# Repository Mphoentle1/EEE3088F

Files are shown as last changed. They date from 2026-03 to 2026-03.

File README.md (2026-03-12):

# EEE3088F
DoA project

This project involves the design and implementation of a high-precision acoustic sensor capable of determining the Direction of Arrival (DoA) of a specific 2000 Hz beacon. The system integrates custom analog front-end hardware with a high-performance STM32F429ZGT6 microcontroller to process signals in real-time under strict latency constraints.

Technical Specifications

Target Frequency: 2000 Hz 
Sampling Rate: 20,000 Hz (5x oversampling for phase accuracy) 
Microphone Spacing: 50 mm
Supply Voltage: 3.3V DC (Strictly compliant with Automated Testing Rig) 
Communication: I2C Slave (Address: 0x42) 
Latency Ceiling: < 50ms from trigger to DoA result 

System Architecture

Analog Front-End
The signal chain uses a Zilltek ZTS6618 top-ported MEMS microphone for superior assembly reliability. The analog path includes:
AC Coupling: Blocks microphone DC offset.Active 
Bandpass Filter: A Multiple Feedback (MFB) topology using the AD8605 rail-to-rail op-amp, providing ~40dB of gain.
DC Biasing: Centering the signal at 1.65V for unipolar ADC sampling.
Digital ProcessingADC Acquisition: High-speed sampling triggered by the Rig state-machine.
DSP Algorithm: Cross-correlation (CCF) performed on the STM32's hardware Floating Point Unit (FPU) to calculate the time-of-flight difference between the microphone pair.
Register Interface: Results are reported via 32-bit IEEE 754 float registers.

📂 Repository Structure

/Hardware: KiCad PCB files, LTspice simulations, and Bill of Materials (BOM).
/Firmware: STM32CubeIDE project (C code), including CMSIS-DSP implementation.
/instruction_sheets: M1 Technical Contract and Physics Baseline proofs.

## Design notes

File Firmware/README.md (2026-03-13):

# DOA Sensor Firmware Implementation Flow

This document outlines the high-level architecture and implementation flow for the Direction of Arrival (DOA) sensor firmware in C/C++.

## 1. Initialization Phase (Startup)

Before accessing peripheral registers, the system must be properly configured.

*   **System Clock & Power:** Enable the system clocks for specific peripherals (ADC, I2C, DMA, GPIO).
*   **GPIO Configuration:**
    *   Set ADC pins to **Analog Input**.
    *   Set I2C pins to **Alternate Function** (SDA/SCL) and configure pull-up resistors if necessary.
*   **I2C Initialization:** Configure the I2C peripheral (slave address, speed, interrupts). This must be done early so it is ready to receive read requests from the external computer at any time.

## 2. ADC Setup Phase

*   **Enable & Calibrate:** Enable the ADC peripheral. Execute a calibration routine immediately after power-on to ensure measurement accuracy.
*   **Configure ADC:** Set the resolution, sampling time, and trigger source.
*   **DMA Configuration (Highly Recommended):** For DOA calculations, high-speed sampling of multiple channels (microphones) is required. Configure a Direct Memory Access (DMA) controller to automatically transfer data from the ADC register to a buffer in memory. This frees the CPU from polling and reading every single sample.

## 3. The Main Execution Loop (State Machine)

*   **Start Sampling:** Trigger the ADC conversion to begin filling the DMA buffer.
*   **Wait for Completion:**
    *   Implement an **Interrupt Service Routine (ISR)** (e.g., `ADC_ConvCpltCallback` or a DMA transfer complete interrupt).
    *   Inside the interrupt, set a volatile flag (`dataReady = true`).
*   **Signal Processing:**
    *   In the main loop, check if `dataReady` is true.
    *   If true, reset the flag and perform the DOA mathematics (FFT, Phase difference calculation, etc.) on the sampled data buffer.
    *   Update a global structure or array with the calculated Angle, Phase, and the Student Number.
    *   *Note: Ensure this structure is updated atomically or double-buffered so the I2C interrupt doesn't read partially updated data.*

## 4. Communication (Asynchronous)

*   **I2C Handling:** Communication with the external computer runs asynchronously in the background via interrupts.
*   **I2C Interrupt Handler:** When the external computer requests a read:
    *   The I2C ISR accesses the global result buffer (Angle, Phase, Student Number).
    *   It transmits this data back to the master.
    *   If a calculation is currently modifying the data, ensure proper data locking/buffering logic is in place.

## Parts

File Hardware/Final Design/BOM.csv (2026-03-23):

Comment | Designator | Footprint | LCSC | Quantity
100K | Rf1,Rf3 | R0805 (RESISTOR) | C149504 | 2
100nF | C12,C13,C14,C15,C16,C23,C24,C25,C26,C27,C5,C6,Cbias1,Cbias2,Cin1,Cin2 | C0805 (CAPACITOR) | C28233 | 16
10K | R1,R15,R16,R17,R2 | R0805 (RESISTOR) | C17414 | 5
10nF | C2,C3,C30,C31 | C0805 (CAPACITOR) | C1710 | 4
10uF | C1,C29,C7 | C0805 (CAPACITOR) | C15850 | 3
1K | Rf2,Rf6 | R0805 (RESISTOR) | C17513 | 2
2.2uF | C11,C4 | C0805 (CAPACITOR) | C377773 | 2
2.7K | Rg2,Rg9 | R0805 (RESISTOR) | C17530 | 2
3.3K | Rg1,Rg3 | R0805 (RESISTOR) | C26010 | 2
4.7K | R3,R9 | R0805 (RESISTOR) | C17673 | 2
4.7uF | C28 | C0805 (CAPACITOR) | C1779 | 1
82K | Rf4,Rf5,Rg4,Rg8 | R0805 (RESISTOR) | C23254 | 4
AD8606ARZ | U1,U4,U5,U6 | AD8606ARZ-REEL7 (OPAMP) | C22365308 | 4
CMM-2718AT-42308-TR | MIC1,MIC2 | XDCR_CMM-2718AT-42308-TR (MIC) | C3171756 | 2
STM32F429ZGTx | U11 | LQFP-144_20x20mm_P0.5mm | C46525 | 1

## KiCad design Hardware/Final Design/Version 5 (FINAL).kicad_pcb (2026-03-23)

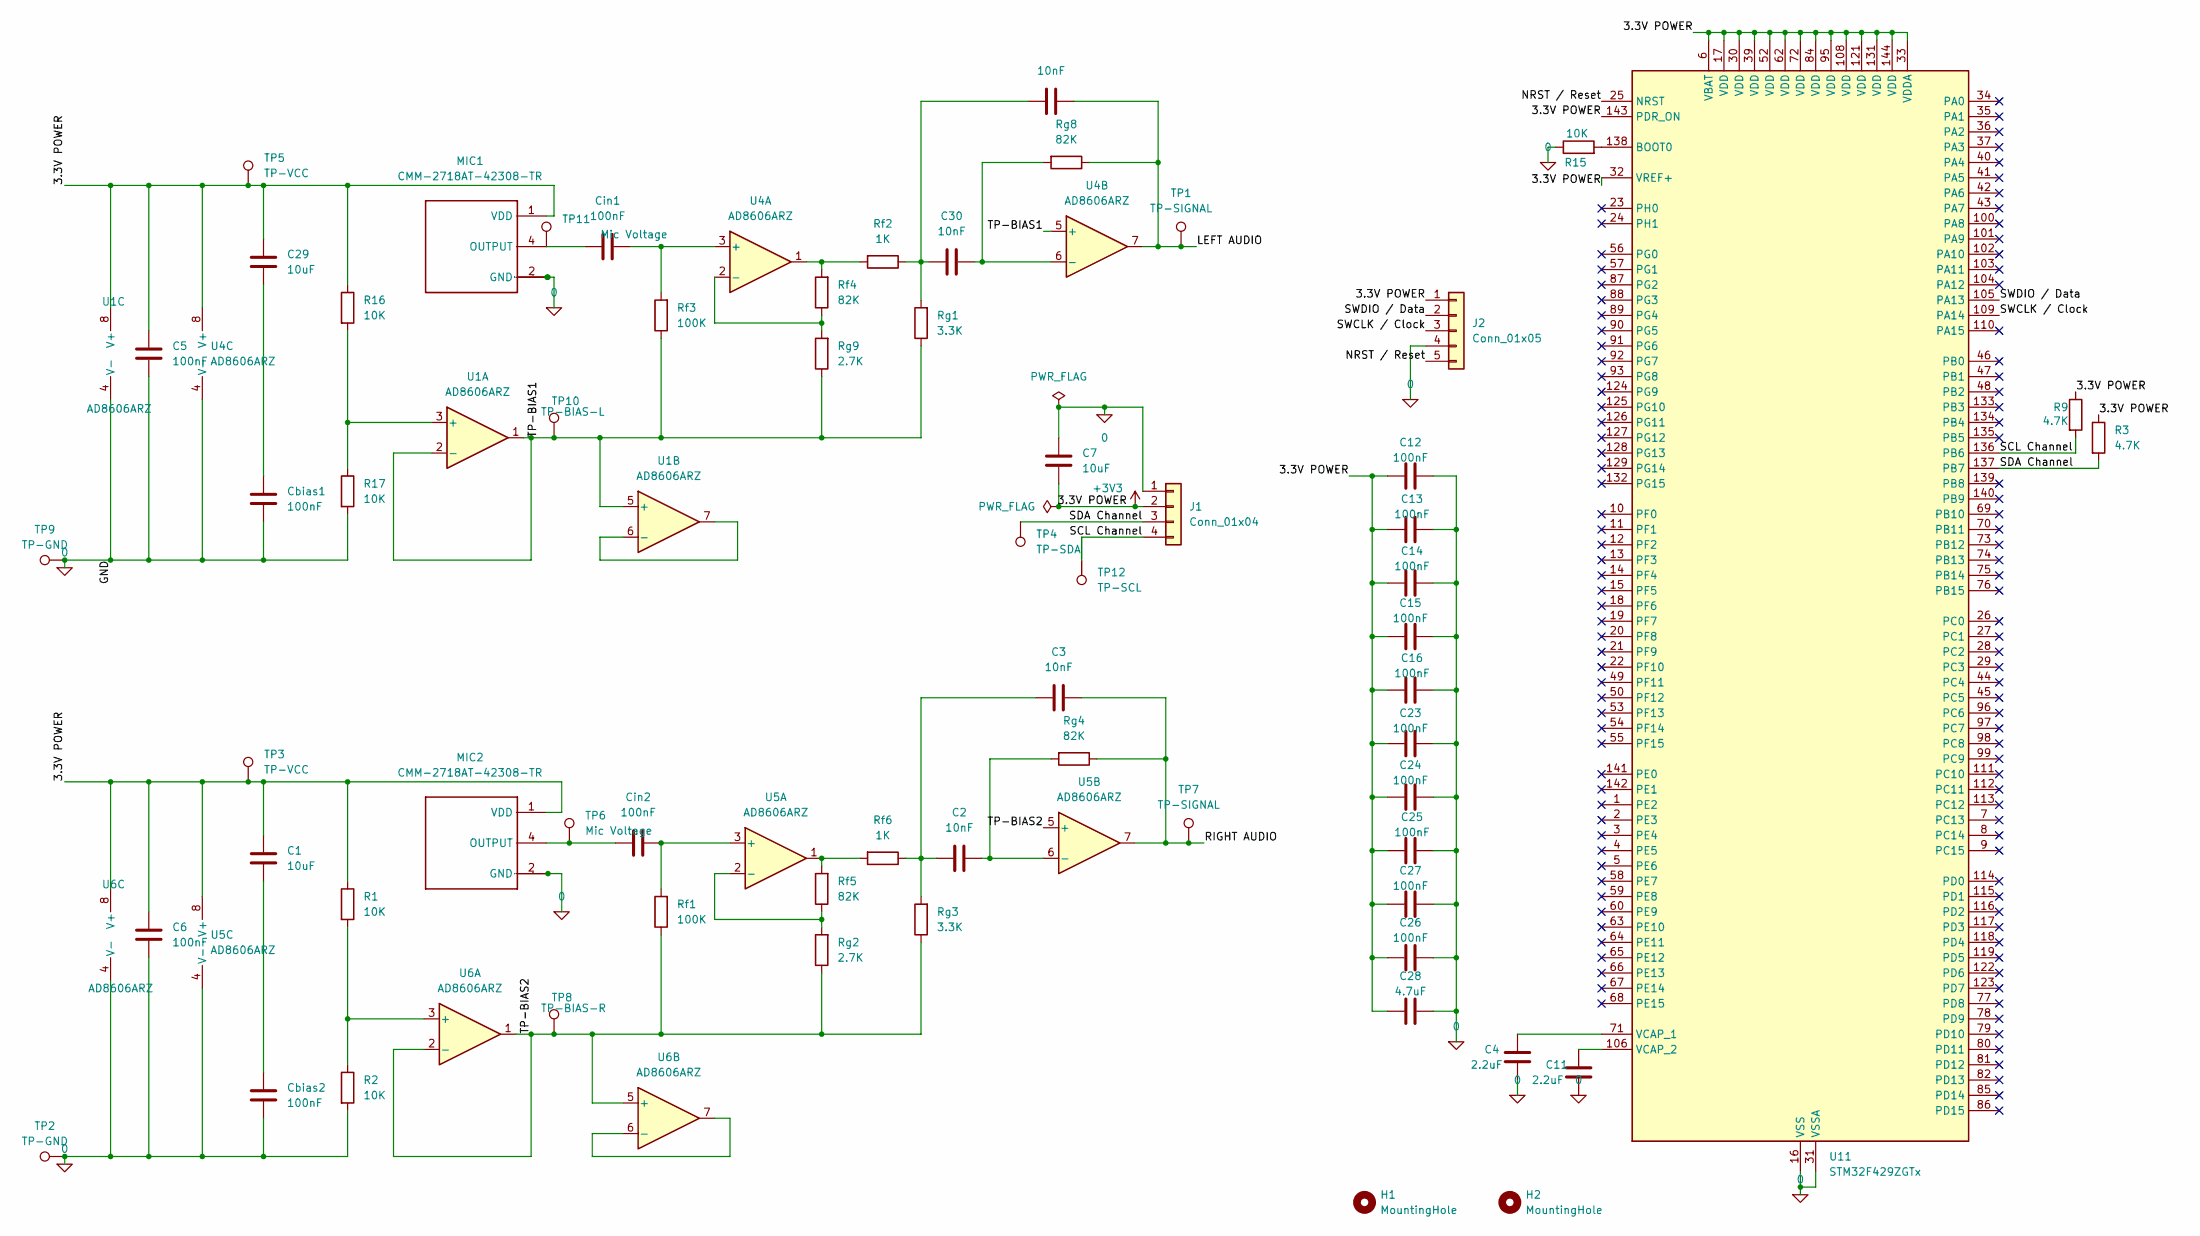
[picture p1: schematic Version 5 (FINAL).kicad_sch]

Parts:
C1, C7, C29: 10uF; C0805 (CAPACITOR); LCSC C1713
C2, C3, C30, C31: 10nF; C0805 (CAPACITOR); LCSC C24666
C4, C11: 2.2uF; C0805 (CAPACITOR); LCSC C1731
C5, C6, C12, C13, C14, C15, C16, C23, C24, C25, C26, C27: 100nF; C0805 (CAPACITOR); LCSC C29926
C28: 4.7uF; C0805 (CAPACITOR); LCSC C1746
Cbias1, Cbias2: 100nF; C0805 (CAPACITOR); LCSC C29926
Cin1, Cin2: 100nF; C0805 (CAPACITOR); LCSC C29926
H1, H2: MountingHole; MountingHole_3.2mm_M3
J1: Conn_01x04; PinHeader_1x04_P2.54mm_Horizontal
J2: Conn_01x05; PinHeader_1x05_P2.54mm_Vertical
MIC1, MIC2: CMM-2718AT-42308-TR; XDCR_CMM-2718AT-42308-TR (MIC); LCSC C3171756
R1, R2, R15, R16, R17: 10K; R0805 (RESISTOR); LCSC C84376
R3, R9: 4.7K; R0805 (RESISTOR); LCSC C17673
Rf1, Rf3: 100K; R0805 (RESISTOR); LCSC C96346
Rf2, Rf6: 1K; R0805 (RESISTOR); LCSC C2904551
Rf4, Rf5: 82K; R0805 (RESISTOR); LCSC C101876
Rg1, Rg3: 3.3K; R0805 (RESISTOR); LCSC C26010
Rg2, Rg9: 2.7K; R0805 (RESISTOR); LCSC C101616
Rg4, Rg8: 82K; R0805 (RESISTOR); LCSC C101876
TP1, TP7: TP-SIGNAL; TestPoint_Pad_2.0x2.0mm
TP2, TP9: TP-GND; TestPoint_Pad_2.5x2.5mm
TP3, TP5: TP-VCC; TestPoint_Pad_2.0x2.0mm
TP4: TP-SDA; TestPoint_Pad_2.0x2.0mm
TP6, TP11: Mic Voltage; TestPoint_Pad_2.0x2.0mm
TP8: TP-BIAS-R; TestPoint_Pad_2.0x2.0mm
TP10: TP-BIAS-L; TestPoint_Pad_2.0x2.0mm
TP12: TP-SCL; TestPoint_Pad_2.0x2.0mm
U1, U4, U5, U6: AD8606ARZ; AD8606ARZ-REEL7 (OPAMP); LCSC C22365308
U11: STM32F429ZGTx; LQFP-144_20x20mm_P0.5mm; LCSC C46525

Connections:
0: C4.1, C5.2, C6.2, C7.2, C11.1, C12.2, C13.1, C14.2, C15.2, C16.2, C23.2, C24.2, C25.2, C26.2, C27.2, C28.2, Cbias1.2, Cbias2.2, J1.1, J2.4, MIC1.2 (GND), MIC1.3 (GND), MIC2.2 (GND), MIC2.3 (GND), R2.2, R15.1, R17.2, TP2.1, TP9.1, U1.4 (V-), U4.4 (V-), U5.4 (V-), U6.4 (V-), U11.16 (VSS), U11.31 (VSSA), U11.38 (VSS), U11.51 (VSS), U11.61 (VSS), U11.83 (VSS), U11.94 (VSS), U11.107 (VSS), U11.120 (VSS), U11.130 (VSS)
+3V3: C1.1, C5.1, C6.1, C7.1, C12.1, C13.2, C14.1, C15.1, C16.1, C23.1, C24.1, C25.1, C26.1, C27.1, C28.1, C29.1, J1.2, J2.1, MIC1.1 (VDD), MIC2.1 (VDD), R1.1, R3.1, R9.1, R16.1, TP3.1, TP5.1, U1.8 (V+), U4.8 (V+), U5.8 (V+), U6.8 (V+), U11.6 (VBAT), U11.17 (VDD), U11.30 (VDD), U11.32 (VREF+), U11.33 (VDDA), U11.39 (VDD), U11.52 (VDD), U11.62 (VDD), U11.72 (VDD), U11.84 (VDD), U11.95 (VDD), U11.108 (VDD), U11.121 (VDD), U11.131 (VDD), U11.143 (PDR_ON), U11.144 (VDD)
/LEFT AUDIO: C31.2, Rg8.1, TP1.1, U4.7
/NRST / Reset: J2.5, U11.25 (NRST)
/RIGHT AUDIO: C3.2, Rg4.1, TP7.1, U5.7
/SCL Channel: J1.4, R9.2, TP12.1, U11.136 (PB6)
/SDA Channel: J1.3, R3.2, TP4.1, U11.137 (PB7)
/SWCLK / Clock: J2.3, U11.109 (PA14)
/SWDIO / Data: J2.2, U11.105 (PA13)
/TP-BIAS1: Rf3.1, Rg1.1, Rg9.1, TP10.1, U1.1, U1.2 (-), U1.5 (+), U4.5 (+)
/TP-BIAS2: Rf1.1, Rg2.1, Rg3.1, TP8.1, U5.5 (+), U6.1, U6.2 (-), U6.5 (+)
unnamed: C1.2, Cbias2.1
unnamed: C2.1, C3.1, Rf6.1, Rg3.2
unnamed: C29.2, Cbias1.1
unnamed: C30.1, C31.1, Rf2.1, Rg1.2
unnamed: Cin1.1, MIC1.4 (OUTPUT), TP11.1
unnamed: Cin2.1, MIC2.4 (OUTPUT), TP6.1
unnamed: Rf2.2, Rf4.2, U4.1
unnamed: Rf5.2, Rf6.2, U5.1
unnamed: R16.2, R17.1, U1.3 (+)
unnamed: U1.6 (-), U1.7
unnamed: Cin1.2, Rf3.2, U4.3 (+)
unnamed: Rf4.1, Rg9.2, U4.2 (-)
unnamed: C30.2, Rg8.2, U4.6 (-)
unnamed: Cin2.2, Rf1.2, U5.3 (+)
unnamed: Rf5.1, Rg2.2, U5.2 (-)
unnamed: C2.2, Rg4.2, U5.6 (-)
unnamed: R1.2, R2.1, U6.3 (+)
unnamed: U6.6 (-), U6.7
unnamed: R15.2, U11.138 (BOOT0)
unnamed: C4.2, U11.71 (VCAP_1)
unnamed: C11.2, U11.106 (VCAP_2)

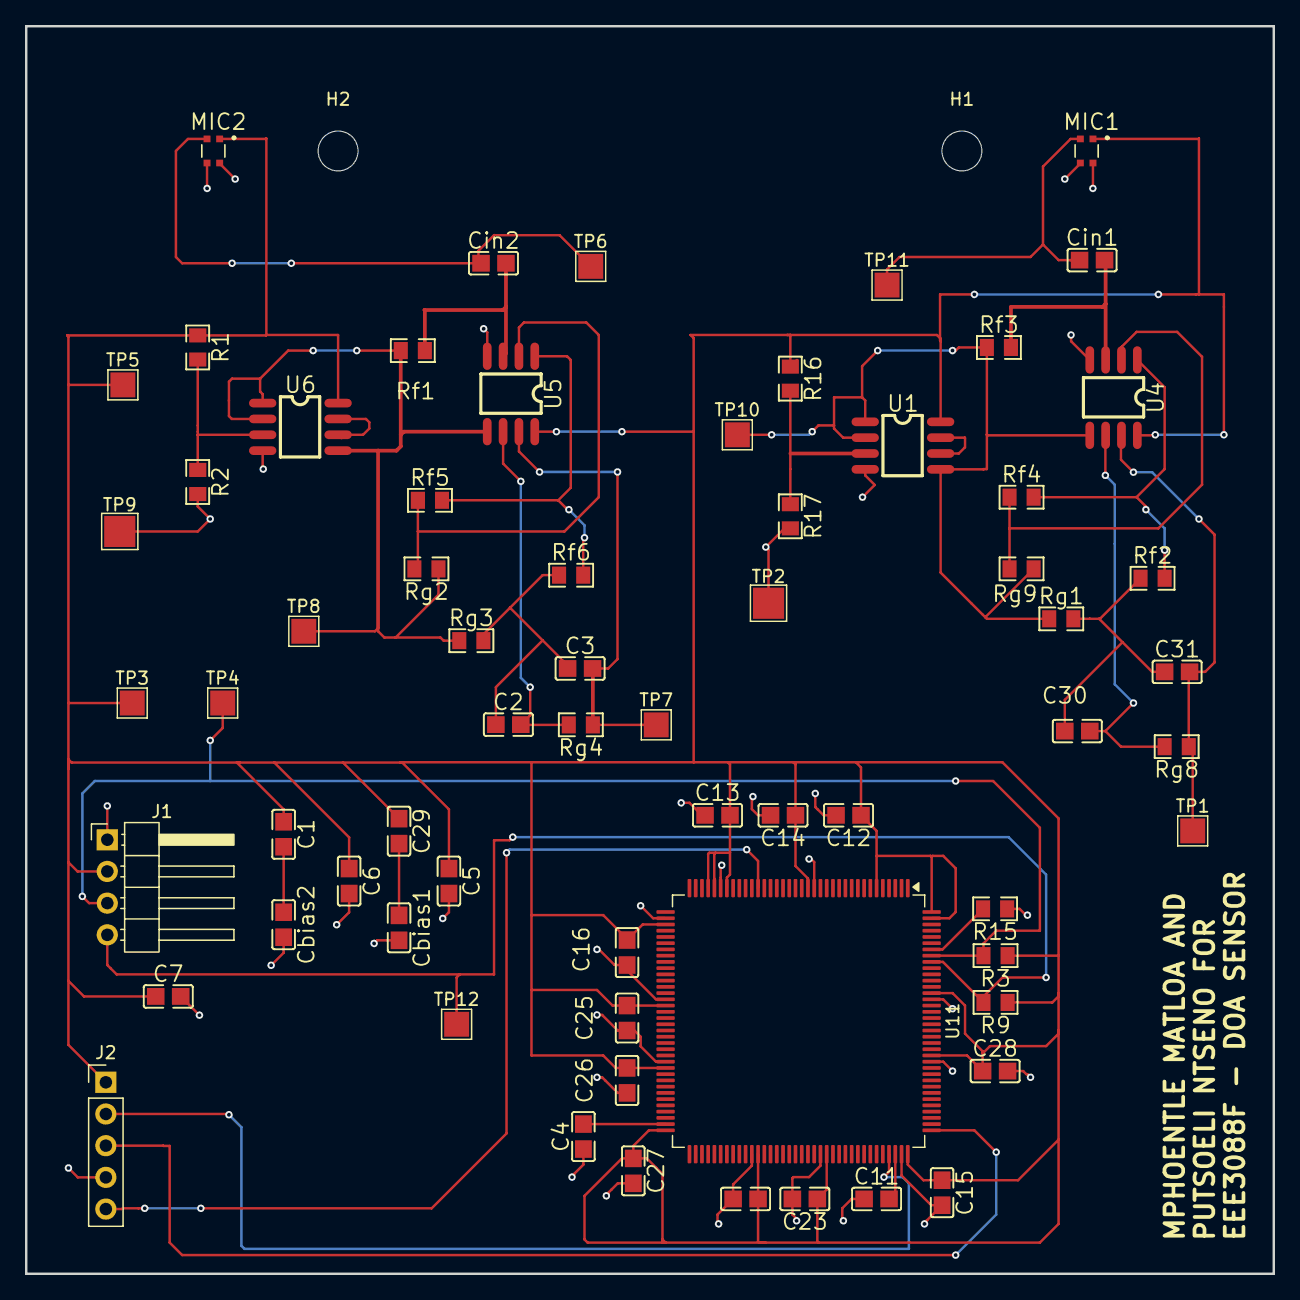
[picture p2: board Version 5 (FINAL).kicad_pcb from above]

Board: 2 copper layers, 100.0 x 100.0 mm, 68 parts (0 on the bottom side), 32 nets.

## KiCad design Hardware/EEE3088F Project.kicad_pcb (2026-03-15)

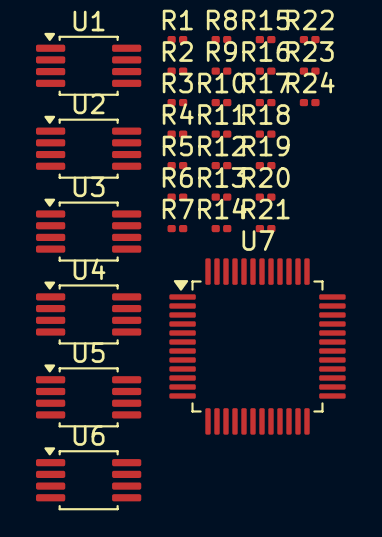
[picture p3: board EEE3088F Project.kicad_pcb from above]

Board: 2 copper layers, 31 parts (0 on the bottom side), 24 nets, no tracks yet.

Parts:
R1, R2, R3, R4, R6, R7, R9, R10, R12, R14, R16, R17, R18, R20, R23: 10K; R_0201_0603Metric
R5, R8, R11, R13, R15, R19, R24: 100K; R_0201_0603Metric
R21, R22: 100; R_0201_0603Metric
U1, U2, U3, U4, U5, U6: OP1177ARM; MSOP-8_3x3mm_P0.65mm
U7: STM32F051C6Tx; LQFP-48_7x7mm_P0.5mm

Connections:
0: R2.2, R4.2, R23.1, U1.4 (V-), U2.4 (V-), U3.4 (V-), U4.4 (V-), U5.4 (V-), U6.4 (V-), U7.8 (VSSA), U7.23 (VSS), U7.47 (VSS)
+3.3V: R1.1, R3.1, R24.2, U1.7 (V+), U2.7 (V+), U3.7 (V+), U4.7 (V+), U5.7 (V+), U7.1 (VBAT), U7.9 (VDDA), U7.24 (VDD), U7.48 (VDD)
/LEFT AUDIO: R5.1, R22.2, U6.6
/RIGHT AUDIO: R19.1, R21.2, U5.6
/SDA Channel: R24.1, U7.43 (PB7)
unnamed: R1.2, R2.1, R9.2
unnamed: R3.2, R4.1, R10.2
unnamed: R11.1, R18.1, U2.6
unnamed: R15.1, R17.1, U1.6
unnamed: R9.1, U1.3 (+)
unnamed: R15.2, R16.1, U1.2 (-)
unnamed: R10.1, U2.3 (+)
unnamed: R11.2, R12.1, U2.2 (-)
unnamed: R17.2, U3.3 (+)
unnamed: R13.2, R14.1, U3.2 (-)
unnamed: R18.2, U4.3 (+)
unnamed: R7.1, R8.2, U4.2 (-)
unnamed: R13.1, U3.6, U5.3 (+)
unnamed: R19.2, R20.1, U5.2 (-)
unnamed: R8.1, U4.6, U6.3 (+)
unnamed: R5.2, R6.1, U6.2 (-)
unnamed: R23.2, U7.44 (BOOT0)
unnamed: R21.1, U7.10 (PA0)
unnamed: R22.1, U7.14 (PA4)

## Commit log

2026-03-13 Create README.md
    Created a hardware folder to put the schematics
2026-03-13 Kicad files upload
    [EEE3088F Project.kicad_pcb, EEE3088F Project.kicad_sch]
2026-03-13 Create opamp.lib
    Creating a model for an opamp for Kicad
2026-03-15 Upload updated files
    [EEE3088F Project.kicad_pcb, EEE3088F Project.kicad_sch]
